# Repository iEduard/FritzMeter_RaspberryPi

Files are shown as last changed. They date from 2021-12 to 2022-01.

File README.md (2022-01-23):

# About
Application used to show the current usage of the up and downstream on two analog gauges

ExampleVideo

See the detailed instructions here: https://www.instructables.com/Fritzmeter/

# Hardware

- Raspberry Pi Zero W
- 2x Adafruit MCP4725 12-Bit DAC  https://learn.adafruit.com/mcp4725-12-bit-dac-tutorial
- 2x 5V Analog gauges

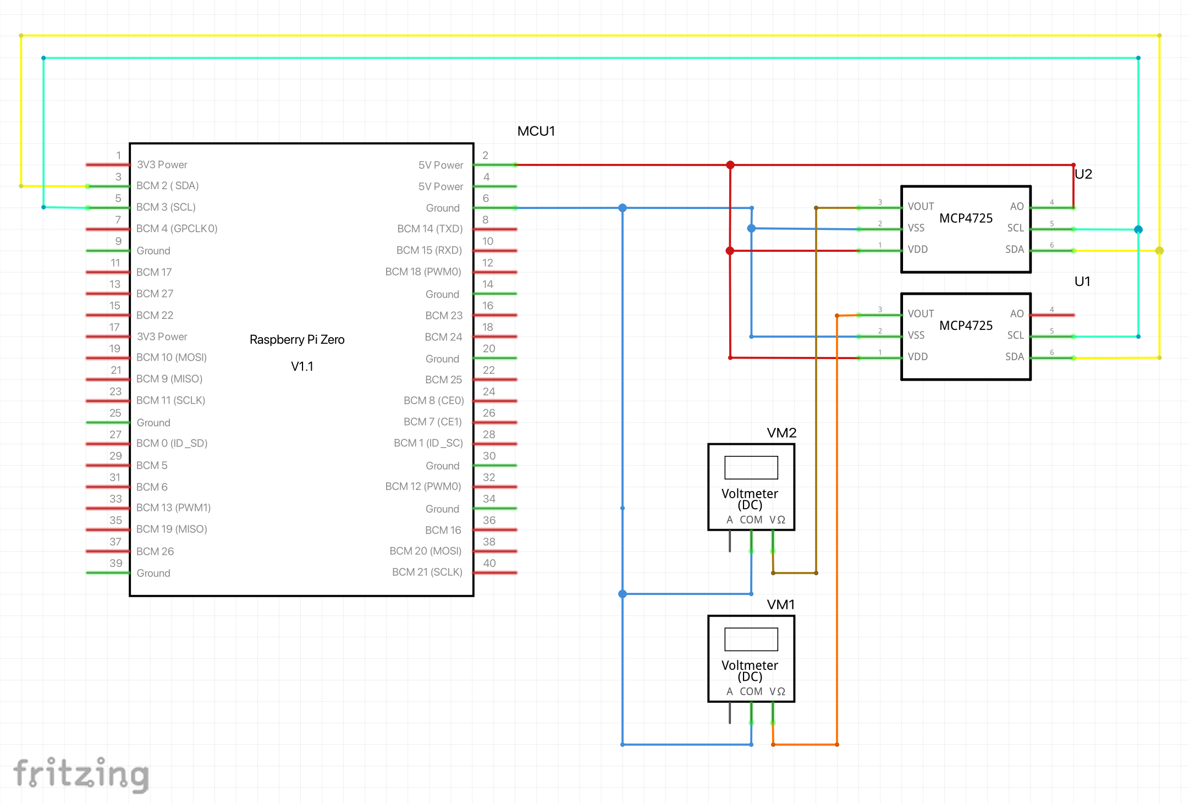
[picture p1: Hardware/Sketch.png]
Sketch


## Gauges Background

The Background of the gauges can be created by the Hardware/Analog Gauges/CreateGaugesBackground.py Python script.

There will be two svg files created. One for the up and one for the download. The script can be edited to suit the network settings.

Sketch

### Using the Python Gauge Background generator

#### Importing the needed libraries

To install pycairo we also need the dependencies of the C Headers. For mac os use:

> brew install cairo pkg-config

For other os´s check this article: https://pycairo.readthedocs.io/en/latest/getting_started.html

After installing the requested c-headers we can install pycairo.

> pip install pycairo

running the python script will create an output and show the file path of the two created files.

> python3 CreateGaugesBackground.py \
> Upload File saved here:/Users/esc/Git/FritzMeter_RaspberryPi/Hardware/upload.svg \
> Download File saved here:/Users/esc/Git/FritzMeter_RaspberryPi/Hardware/download.svg \
> Done

The output can be changed with the global constants ad the top

    UPLOAD_FILE_NAME = "upload.svg"
    DOWNLOAD_FILE_NAME = "download.svg"

    #Define the metrics of the gauge
    MAX_DOWNLOAD_SPEED = 200		#Set the max download speed here
    MAX_UPLOAD_SPEED = 30			#Set the max upload speed here

    BACKGROUND_SIZE_X = 650			#Fixed background settings. Do not change these.
    BACKGROUND_SIZE_Y = 400			#Fixed background settings. Do not change these.

    #Define the style of the gauges  
    FONT_LABEL = "Helvetica"			#Font of the labels
    FONT_LABEL_SIZE = 40				#Font size of the labels
    FONT_DESCRIPTION = "Helvetica"		#Font of the description
    FONT_DESCRIPTION_SIZE = 48			#Font size of the description

    UPLOAD_AXIS_DEVISION = 6			#Divisions of the upload gauges labels
    DOWNLOAD_AXIS_DEVISION = 4			#Divisions of the upload gauges labels

# Software

The application is written in python.

## fritzconnection

To connect with the fr!tz box routers we need an TR-064 libtrary to communicate. This Library can be used to retriev all needed informations drom the router.

## adafruit-circuitpython-mcp4725

### Usage / Info 

- GitHub: https://github.com/adafruit/Adafruit_CircuitPython_MCP4725

- Library Definition: https://circuitpython.readthedocs.io/projects/mcp4725/en/latest/api.html
- Create an SPI object: https://circuitpython.readthedocs.io/en/latest/shared-bindings/busio/index.html#busio.I2C

## netifaces

### Usage / Info

- Library Definition: https://0xbharath.github.io/python-network-programming/libraries/netifaces/index.html

# Pi Konfiguration

After installing the latest Raspbian OS from RaspberryPi.org update the systenm by:

>$ sudo apt-get update
> 
>$ sudo apt-get upgrade

## Install the requested libraries

>$ pip install fritzconnection adafruit-circuitpython-mcp4725 netifaces

## Create and start service

Source: https://www.nerdynat.com/programming/2019/run-python-on-your-raspberry-pi-as-background-service/

>$ sudo nano /lib/systemd/system/fritzmeter.service

Add the text from ./Software/Fritzmeter.service
Than change the permission

>$ sudo chmod 644 /lib/systemd/system/fritzmeter.service

Reload the system manager configuration

>$ sudo systemctl daemon-reload

Start the Service

>$ sudo systemctl start fritzmeter.service

Enable the service to start at boot 

>$ sudo systemctl enable fritzmeter.service

So stop the service you can use

>$ sudo systemctl stop fritzmeter.service

# Background light

Additionally you can add an led backlight and control it with an button. In the script the button ist set to Pin 17 and the led's on pin 18 and 27.

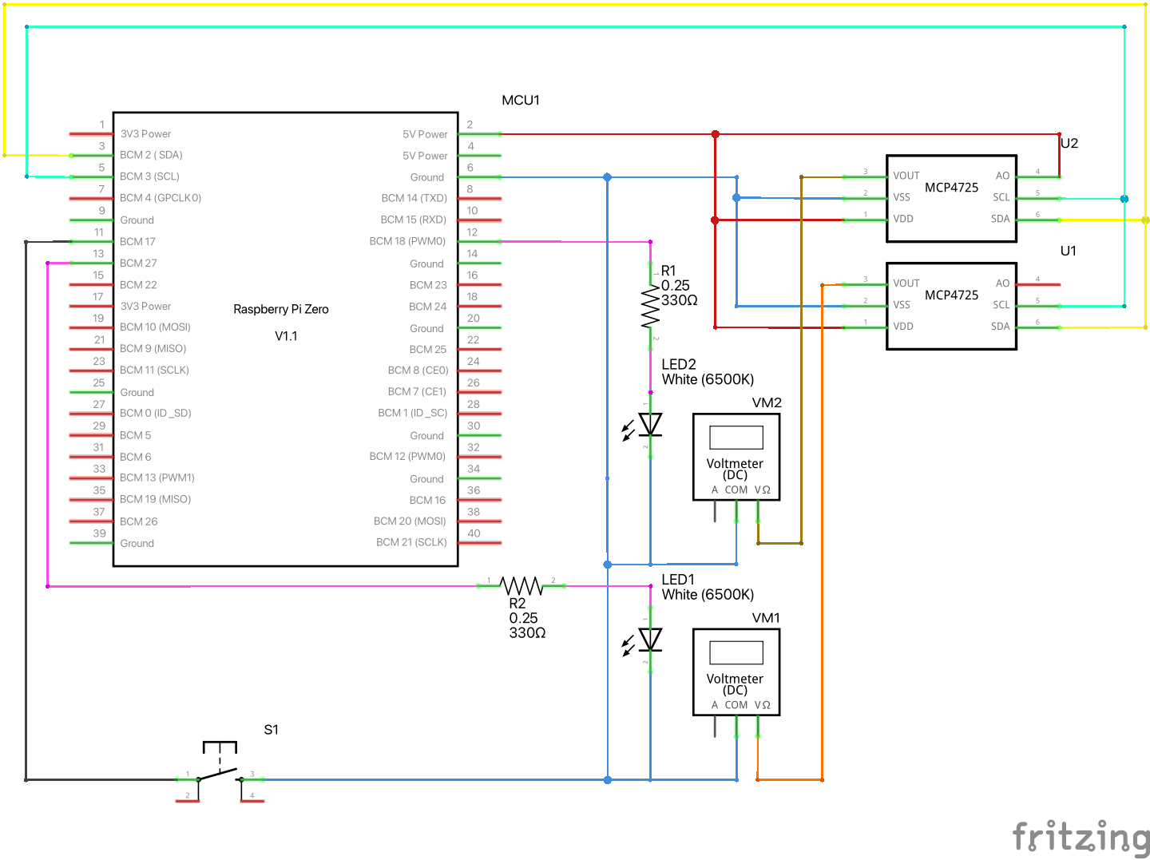
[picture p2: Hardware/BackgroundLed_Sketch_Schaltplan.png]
Sketch


The requested _gpiozero_ lib should be installed with the pi os. If not you can add it with:

> pip install gpiozero

## Add the service for the Background light control

>$ sudo nano /lib/systemd/system/Background_Light.service

Add the text from ./Software/Background_Light.service
Than change the permission

>$ sudo chmod 644 /lib/systemd/system/Background_Light.service

Reload the system manager configuration

>$ sudo systemctl daemon-reload

Start the Service

>$ sudo systemctl start Background_Light.service

Enable the service to start at boot 

>$ sudo systemctl enable Background_Light.service

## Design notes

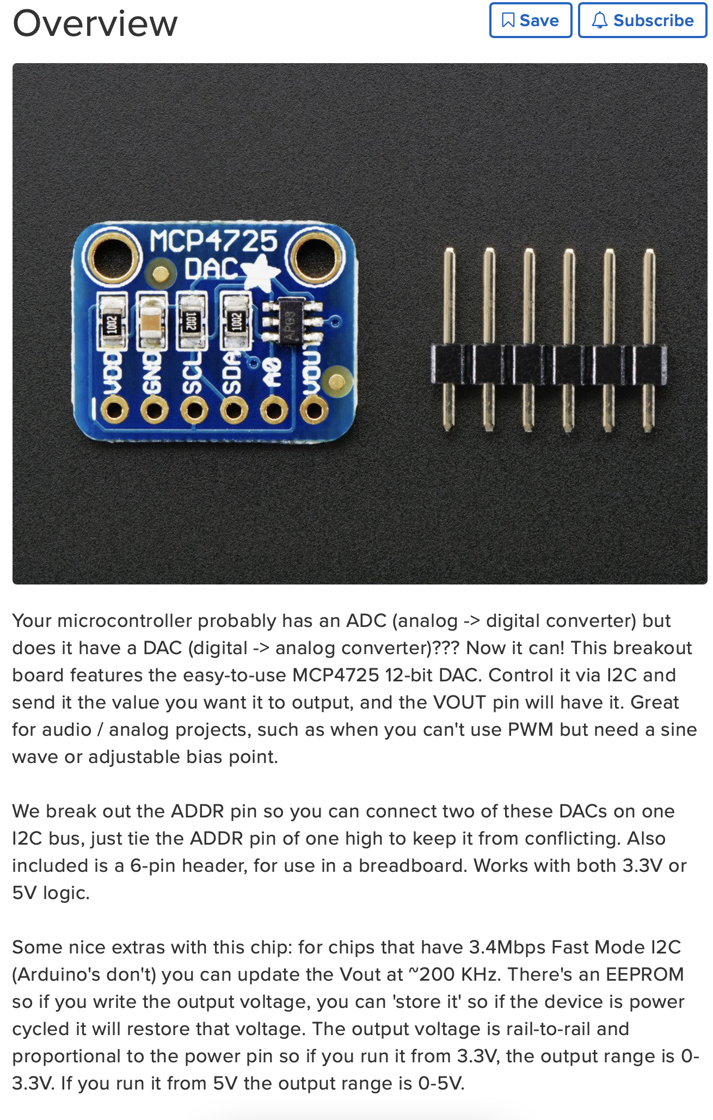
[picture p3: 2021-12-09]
Hardware/DAC/Adafruit Beschreibung.png

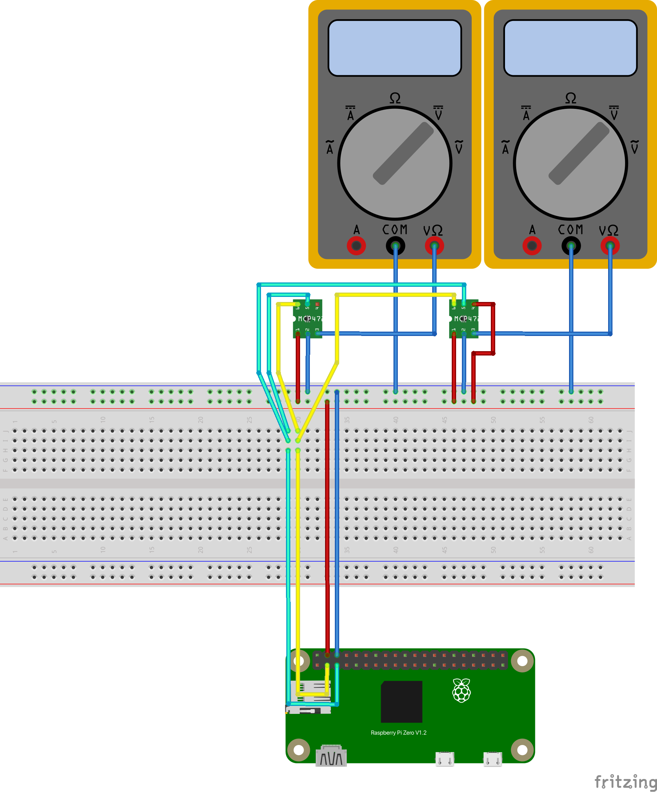
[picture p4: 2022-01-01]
Hardware/Steckplatine.png

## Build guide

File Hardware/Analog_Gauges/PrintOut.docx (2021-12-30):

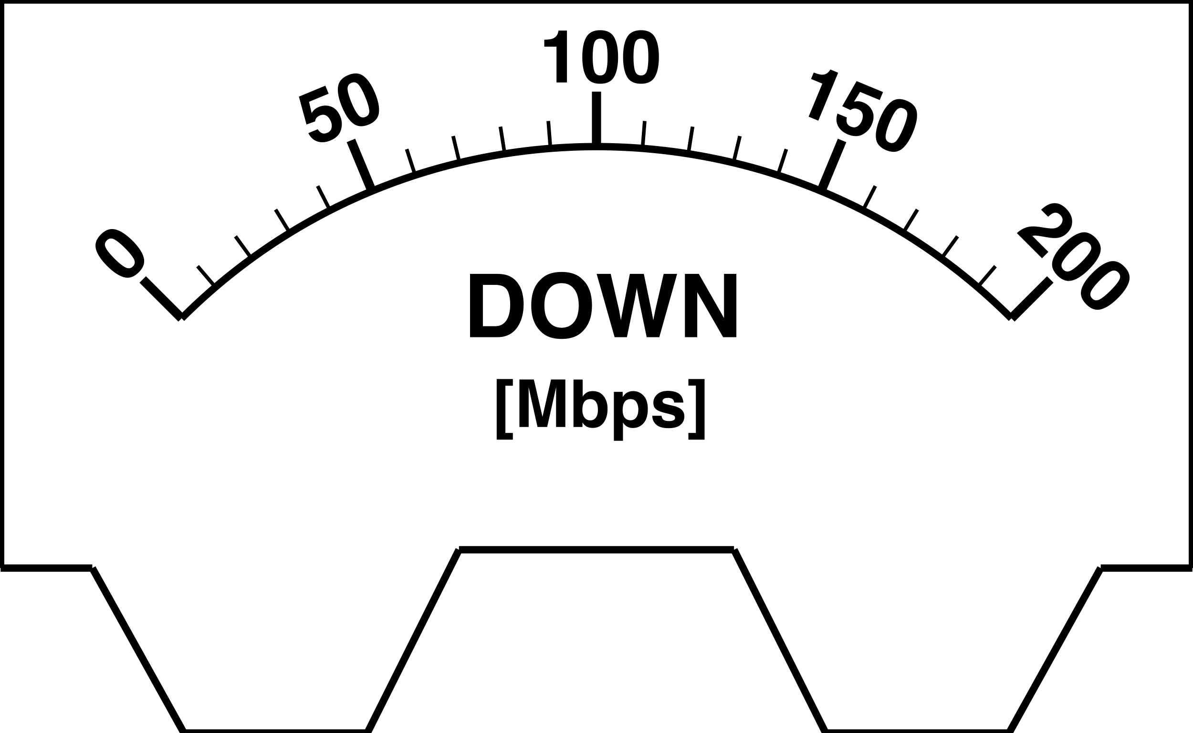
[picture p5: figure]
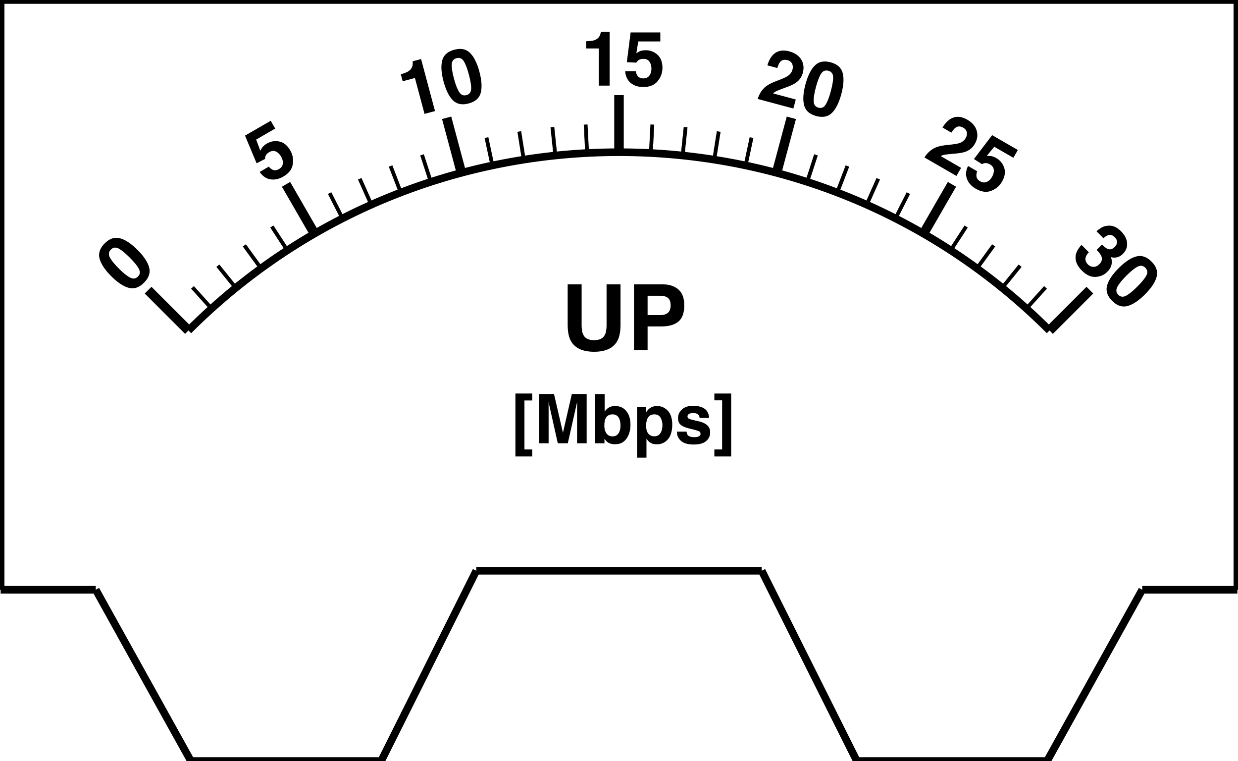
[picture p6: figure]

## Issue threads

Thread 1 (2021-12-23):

Get the IP Address from the DHCP Server instead of the fix Address entered in the Program

iEduard, 2021-12-23:
Try to read the IP Address from the Router instead of write them fix to the program. With this we only need to change the max up and downloads.

iEduard, 2021-12-24:
Found this helpful article:

https://www.tutorialexample.com/python-get-default-gateway-ip-using-netifaces-a-step-guide-python-tutorial/

This is using netifaces

Installing the packages:

`pip install netifaces`

Example code:

```
import netifaces

# gets gateway of the network
gws = netifaces.gateways()

gateway = gws['default'][netifaces.AF_INET][0]
print(gateway)
```

iEduard, 2021-12-31:
Updated the code and the ready me.

Closed 2021-12-31.

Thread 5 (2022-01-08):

Can not install pycairo on MacOS Catalina

SchneHa, 2022-01-08:
Firing the command pip install pycairo or pip3 install pycairo is throwing an error:
```
DEPRECATION: Configuring installation scheme with distutils config files is deprecated and will no longer work in the near future. If you are using a Homebrew or Linuxbrew Python, please see discussion at https://github.com/Homebrew/homebrew-core/issues/76621
Collecting pycairo
  Using cached pycairo-1.20.1.tar.gz (344 kB)
  Installing build dependencies ... done
  Getting requirements to build wheel ... done
  Preparing metadata (pyproject.toml) ... done
Building wheels for collected packages: pycairo
  Building wheel for pycairo (pyproject.toml) ... error
  ERROR: Command errored out with exit status 1:
   command: /usr/local/opt/python@3.9/bin/python3.9 /usr/local/lib/python3.9/site-packages/pip/_vendor/pep517/in_process/_in_process.py build_wheel /var/folders/xd/qt0vz41n66n1cmpbn4d75n_r0000gn/T/tmp4y3jwk6f
       cwd: /private/var/folders/xd/qt0vz41n66n1cmpbn4d75n_r0000gn/T/pip-install-no549gg4/pycairo_3634aa03d87b4dcd9a999a933f576373
  Complete output (15 lines):
  running bdist_wheel
  running build
  running build_py
  creating build
  creating build/lib.macosx-10.15-x86_64-3.9
  creating build/lib.macosx-10.15-x86_64-3.9/cairo
  copying cairo/__init__.py -> build/lib.macosx-10.15-x86_64-3.9/cairo
  copying cairo/__init__.pyi -> build/lib.macosx-10.15-x86_64-3.9/cairo
  copying cairo/py.typed -> build/lib.macosx-10.15-x86_64-3.9/cairo
  running build_ext
  Package gobject-2.0 was not found in the pkg-config search path.
  Perhaps you should add the directory containing `gobject-2.0.pc'
  to the PKG_CONFIG_PATH environment variable
  Package 'gobject-2.0', required by 'cairo', not found
  Command '['pkg-config', '--print-errors', '--exists', 'cairo >= 1.15.10']' returned non-zero exit status 1.
  ----------------------------------------
  ERROR: Failed building wheel for pycairo
Failed to build pycairo
ERROR: Could not build wheels for pycairo, which is required to install pyproject.toml-based projects

```
What goes wrong or better: How to avoid this?

iEduard, 2022-01-08:
Did you install the required dependencies? You can do this wit brew by entering:

brew install cairo pkg-config

It took me a while to figure out that you need the c lib in order to install the python lib 😅

SchneHa, 2022-01-08:
Of course I did. The package 'gobject-2.0' seems not to be in the path but I don't know where it is and how to put it in the path.

iEduard, 2022-01-08:
Try:

brew install glib

Found here: https://github.com/Automattic/node-canvas/issues/1531

SchneHa, 2022-01-08:
```
Hans-MacBook-Pro:~ hasch$ brew install glib
Running `brew update --preinstall`...
Warning: glib 2.70.2 is already installed, it's just not linked.
To link this version, run:
  brew link glib
```
and:
```
Hans-MacBook-Pro:~ hasch$ brew link glib
Linking /usr/local/Cellar/glib/2.70.2...
Error: Could not symlink share/gdb/auto-load
/usr/local/share/gdb is not writable.
```

SchneHa, 2022-01-08:
OK, solved:

`Hans-MacBook-Pro:share hasch$ cd /usr/local/share/gdb`

```
Hans-MacBook-Pro:gdb hasch$ brew link glib
Linking /usr/local/Cellar/glib/2.70.2... 159 symlinks created.
```

```
Hans-MacBook-Pro:gdb hasch$ pip3 install pycairo
DEPRECATION: Configuring installation scheme with distutils config files is deprecated and will no longer work in the near future. If you are using a Homebrew or Linuxbrew Python, please see discussion at https://github.com/Homebrew/homebrew-core/issues/76621
Collecting pycairo
  Using cached pycairo-1.20.1.tar.gz (344 kB)
  Installing build dependencies ... done
  Getting requirements to build wheel ... done
  Preparing metadata (pyproject.toml) ... done
Building wheels for collected packages: pycairo
  Building wheel for pycairo (pyproject.toml) ... done
  Created wheel for pycairo: filename=pycairo-1.20.1-cp39-cp39-macosx_10_15_x86_64.whl size=90762 sha256=004de01dbb593642996f90fa8344eef54efd4e32cd7a301d0be0b05fa4779157
  Stored in directory: /Users/hasch/Library/Caches/pip/wheels/29/a9/b9/15e3dc25ce0db1d40546014674ee0cac132f94bf3a9607d02b
Successfully built pycairo
Installing collected packages: pycairo
DEPRECATION: Configuring installation scheme with distutils config files is deprecated and will no longer work in the near future. If you are using a Homebrew or Linuxbrew Python, please see discussion at https://github.com/Homebrew/homebrew-core/issues/76621
Successfully installed pycairo-1.20.1

```

Closed 2022-01-08.

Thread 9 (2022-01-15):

Toggle LEDs

SchneHa, 2022-01-15:
Switch LEDs as illumination for the instruments  on and off with a momentary push button.

iEduard, 2022-01-20:
The https://github.com/iEduard/FritzMeter_RaspberryPi/blob/backlight/Software/Background_Light.py script was updated in the branch.

Script was tested with the pi 4.

SchneHa, 2022-01-20:
It works GREAT even with Pi Zero with GPIO27 for button and GPIO17 for LED.

iEduard, 2022-01-23:
Merged the Branch in to the main branch.
README was updated,
HW description was added
LED control script was updated with an additional LED.

Closed 2022-01-23.

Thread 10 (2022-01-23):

Background light

SchneHa, 2022-01-23:
I think it's a good idea to limit the current through LED(s). I took a 390 Ohm resistance and a current limiting diode in series with the LED(s). One resistor in GND line is sufficient. I use 2 diodes in GPIO line(s).

iEduard, 2022-01-23:
Thank you for the feedback. I forgot to put them in completely. I added them to the schematic.

Depending on the different LED's current Requirements, it is maybe better to split them and put them on one gpio each.

iEduard, 2022-02-12:
Fixed the schematics and updated the readme

Closed 2022-02-12.

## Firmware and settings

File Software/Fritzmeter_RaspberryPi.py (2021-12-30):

import time
from fritzconnection.lib.fritzstatus import FritzStatus
import board
import busio
import adafruit_mcp4725
import threading
import netifaces

def main():
    """Main program"""

    SLEEP_TIMER_SECONDS = 1
    MAX_UPLOAD_MBPS = 30        #chose the right maximum upload speed depending on your connection
    MAX_DOWNLOAD_MBPS = 200     #chose the right maximum download speed depending on your connection

    #initialize the I2C connection with the sensor
    i2c = busio.I2C(board.SCL, board.SDA)
    dacUpload = adafruit_mcp4725.MCP4725(i2c)
    dacDownload = adafruit_mcp4725.MCP4725(i2c, address=0x63)

    #Get the ip address from the DHCP Server
    fritzIpAddress = netifaces.gateways()['default'][netifaces.AF_INET][0]


    #Create an Fritz Status Object
    fc = FritzStatus(address=fritzIpAddress, password="")

    blnLoopActive = True
    _valueUploadOld = 0
    _valueDownloadOld = 0
    _valueUpload = 0
    _valueDownload = 0
    uploadTransitionThread = None
    downloadTransitionThread = None


    #Start the loop
    while blnLoopActive:


        try:
            #Get the Transmission rate from the Fr!tz Router           
            _transmissionRate = fc.transmission_rate

            #Try to join the Thread if allready existing
            if not (uploadTransitionThread is None): 
                uploadTransitionThread.join()
            if not (downloadTransitionThread is None):
                downloadTransitionThread.join()

            #Convert to value to set the do dac 
            _valueUpload = convertToAnalogOutput(30, convertToMbps(_transmissionRate[0])) 
            _valueDownload = convertToAnalogOutput(200, convertToMbps(_transmissionRate[1]))

            #Create the threads to performane the transition of the analog gauges
            uploadTransitionThread = threading.Thread(target=transition, args=(dacUpload, _valueUploadOld, _valueUpload, 0.8, "Upload",))
            downloadTransitionThread = threading.Thread(target=transition, args=(dacDownload, _valueDownloadOld, _valueDownload, 0.8, "Download",))

            #Start the 
            uploadTransitionThread.start()
            downloadTransitionThread.start()

            #Save the current value 
            _valueUploadOld = _valueUpload
            _valueDownloadOld = _valueDownload
        
        except:
            #Create an Fritz Status Object
            fc = FritzStatus(address='192.168.178.1', password="")
            print("Error occurred. We will not try again.")

def convertToAnalogOutput(maxMbps, currentMbps):
    """
    Convert Mbps to Analog Output over I2C
    """
    tmpRetVal = 0
    #if (currentMbps < 1):
    #    tmpRetVal = 0
    #elif (float(currentMbps) > float(maxMbps)):
    #    tmpRetVal = 1
    #else:

    tmpRetVal = 65535/float(maxMbps)*float(currentMbps)

    return tmpRetVal


def convertToMbps(bytesPerSeconds):
    """
    BytesPerSeconds = Input 
    ---
    Convert the Data (bytes per second) to Mbps Mega bits per second 
    """

    #1 Mega bit per Second (Mbps) = 1 000 000 Bits / Second
    #First convert to Bit (1 Byte = 8 Bit) Than convert to Mbps by divide with 1´000´000
    return (bytesPerSeconds * 8)/1000000


def transition(dac, currentValue, newValue, timeSpan, name):
    """
    transition between the analog values
    Do this to prevent jumping pointer
    """

    intIterations = timeSpan/0.1
    blnCountUp = False
    lastValue = currentValue

    if (lastValue < newValue):
        blnCountUp = True

        valueDiff = (abs(newValue) - abs(lastValue)) / intIterations

    else:

        valueDiff = (abs(lastValue) - abs(newValue)) / intIterations

    for idx in range(int(intIterations)):

        if blnCountUp:
            currentValue = currentValue + valueDiff
        else:
            currentValue = currentValue - valueDiff
    
        #Set the Analog Value
        dac.value = int(currentValue)

        #wait for 100 ms 
        time.sleep(0.1)


if __name__ == '__main__':

    #Start the main program
    main()

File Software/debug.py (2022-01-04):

import time
from fritzconnection.lib.fritzstatus import FritzStatus

def main():
    """Main program"""

    fc = FritzStatus(address="192.168.178.1", password="")
    _transmissionRate = fc.transmission_rate
    _maxTransmitionRate = fc.max_bit_rate

    print("Upload: " + str(_transmissionRate[0]) + " Max Rate: " + str(_maxTransmitionRate[0]/1000000))
    print("Download: " + str(_transmissionRate[1]) + " Max Rate: " + str(_maxTransmitionRate[1]/1000000))

if __name__ == '__main__':

    #Start the main programm
    main()

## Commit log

2021-11-30 Added Arduino Uno Sketch
2021-12-04 Updated the readme and added the Raspberry py python script. Change Project to hanbdle Raspberry Pi controller instead of the arduino yun This is caused do to the lag of the TR064 library
2021-12-13 Added threads to performe the transitions of the gauges Added try Catch to handle errors
2021-12-14 Reorganized the repository Removed the Arduino parts Removed the TR-064 Dokumentation
2021-12-14 Added the Hardware Sketch Updated the Readme
    [FritzMeter_Sketch.fzz]
2021-12-14 -Added the Service for the python board -updated the Readme to confirm the Services
2021-12-17 Re initiated the connection the the fritzbox after an error
    [Fritzmeter_RaspberryPi.py]
2021-12-30 fixed some spelling errors
    [Fritzmeter_RaspberryPi.py]
2022-01-01 Added the breadboard sketch
    [FritzMeter_Sketch.fzz]
2022-01-10 Added current pathoutput Added constant to set the output file names
2022-01-18 Added the loop to continuously control the led
2022-01-20 Updated the Backlight script and tested with the Raspberry pi 4
2022-01-23 Updated the LED Control part of the readme Updated the Background light to control two leds Added the HW Sketch
    [BackgroundLed_Sketch.fzz]
2022-01-23 Fixed the hardware schematic with the background LED. Thx to @SchneHa
    [BackgroundLed_Sketch.fzz]
